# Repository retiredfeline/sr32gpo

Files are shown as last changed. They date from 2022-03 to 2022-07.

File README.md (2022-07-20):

# Shift register 32 general purpose output board

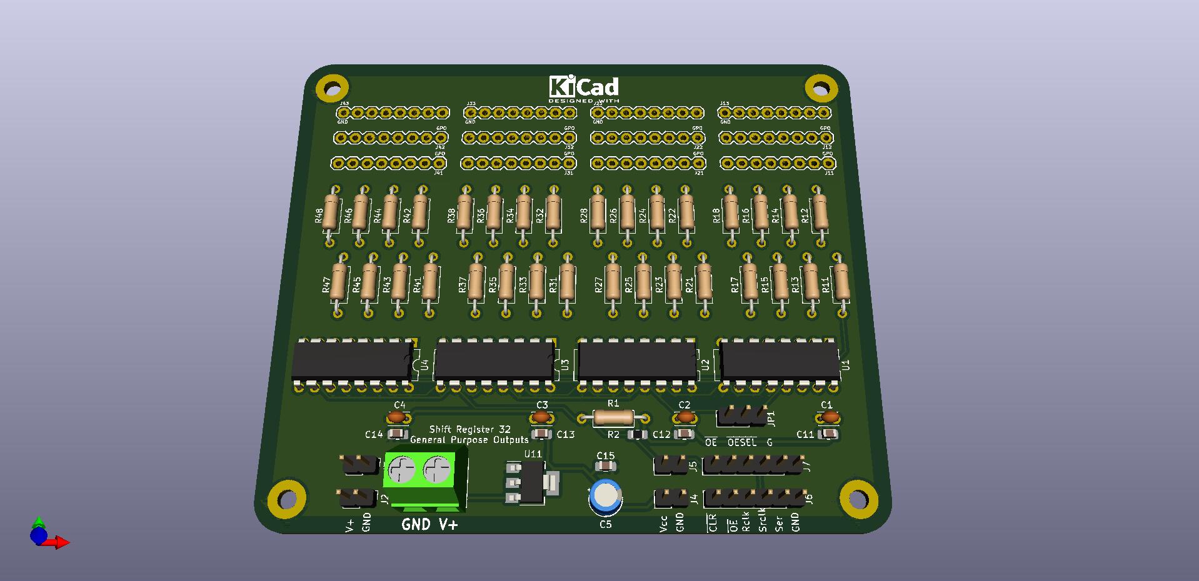
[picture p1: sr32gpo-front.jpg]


These are the Kicad design files for the Shift register 32 bit general purpose output board described in my [Hackaday project page](https://hackaday.io/project/184239-3-line-to-32-line-output-expander).

## Versioning

THT version February 2022

## Notes

The minimum lines required to use this board are: GND, SER (data), SRCLK (shift), RCLK (strobe). Vcc depends on the power arrangement. You should jumper the ~OESEL (output enable select) to ground if you don't wish to disable the display by signal, or vary the output with PWM, from a controller. The ~SRCLR input is only needed for resetting the output by the controller.

This board is designed with optional aspects you can choose to include or not:

- As mentioned some lines don't need to be driven in smaller configurations.

- Between 1 and 4 74HC595s can be installed for 8-32 outputs, in steps of 8. Naturally only the resistors for the used outputs need to be installed.

- The 74HC595 can source or sink 6 mA current.

- The 74HC595 can operate between 2V and 6V. This can be chosen to suit the controller, e.g. 3.3V or 5V, and the power supply section if installed.

- The power supply section is optional. You can choose to power this from the controller. Or you could power the controller with this.

- Copper pads for data and output are duplicated so you can attach more connectors or even solder wires. The input power is also brought out to duplicate pads for piggybacking to other circuits, e.g. an auxiliary board.

- Although the connectors are rendered as vertical pin headers, you can use other kinds of connectors like pin sockets, or even solder wires to the pads.

## Authors

* **Ken Yap**

## License

See the [LICENSE](LICENSE.md) file for license rights and limitations (MIT).

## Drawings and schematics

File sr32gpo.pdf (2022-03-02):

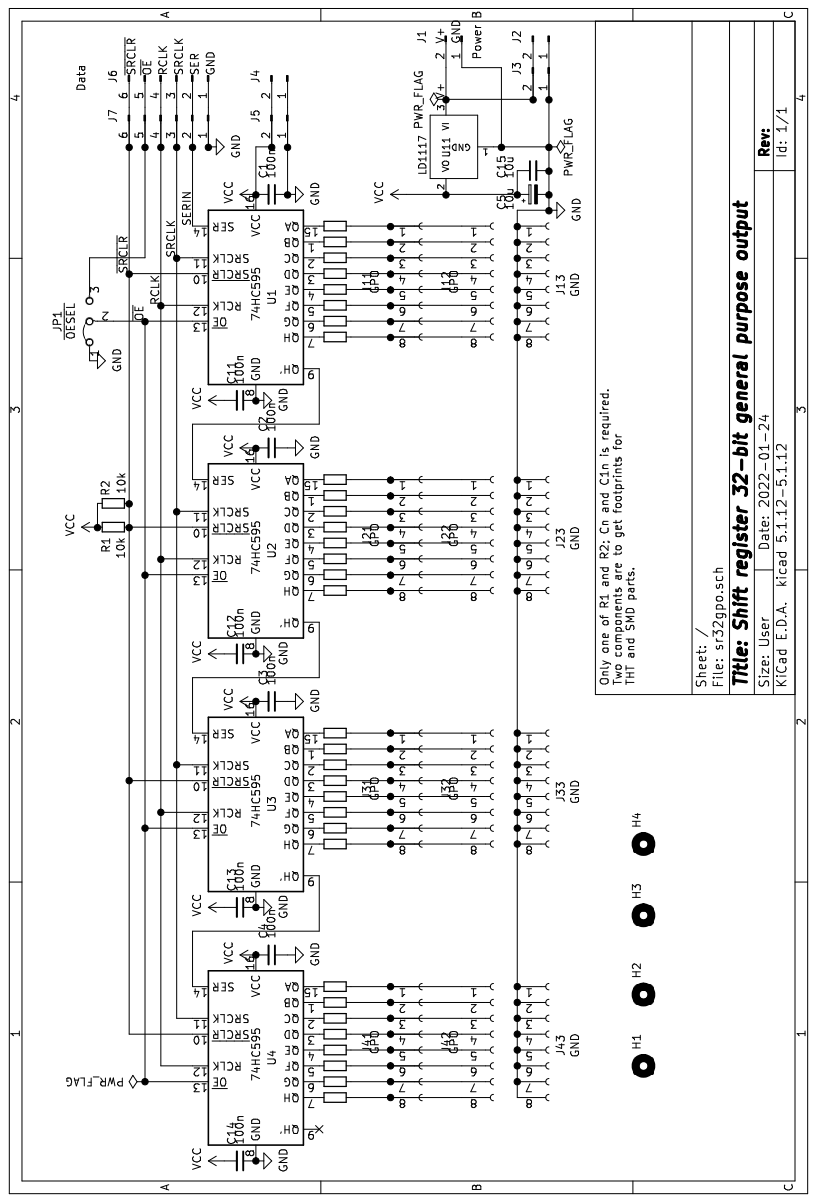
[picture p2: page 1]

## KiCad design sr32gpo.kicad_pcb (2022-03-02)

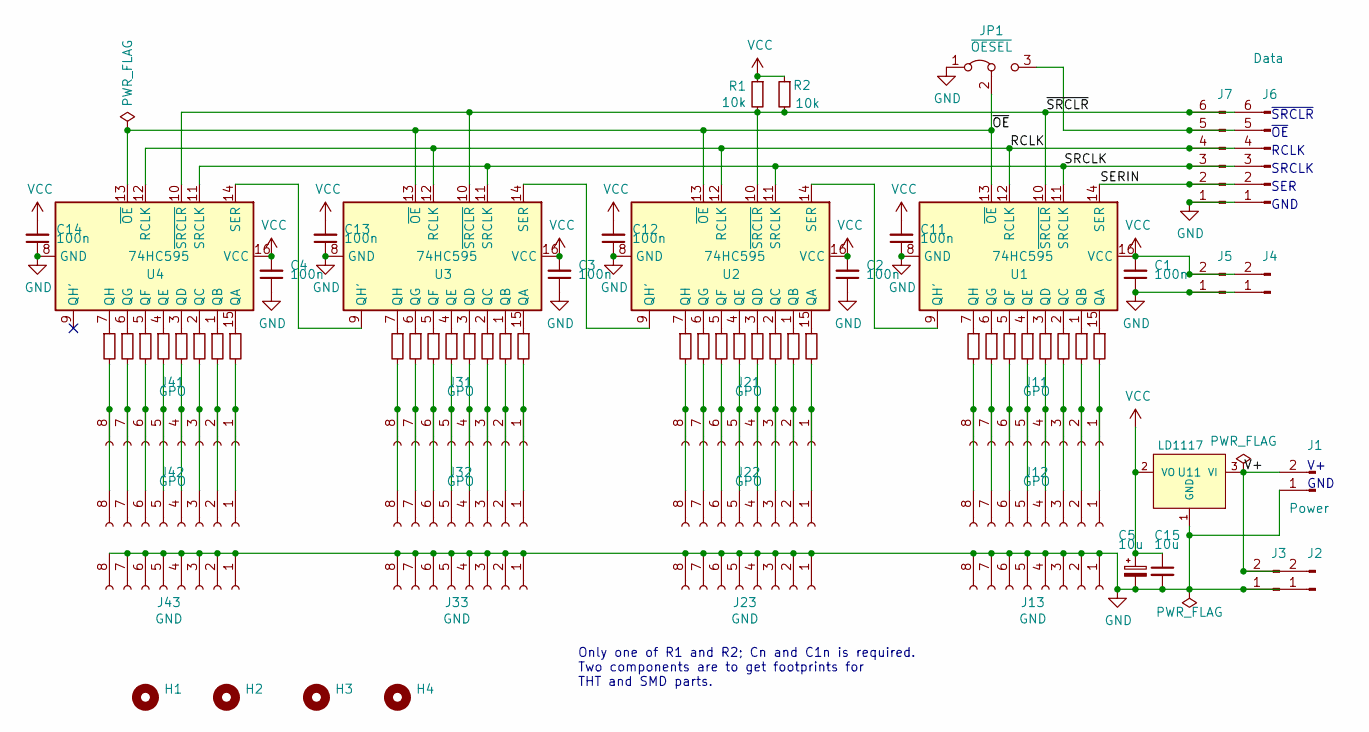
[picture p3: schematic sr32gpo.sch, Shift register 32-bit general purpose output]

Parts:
C1, C2, C3, C4: 100n; C_Disc_D3.0mm_W2.0mm_P2.50mm
C5: 10u; CP_Radial_D5.0mm_P2.50mm
C11, C12, C13, C14: 100n; C_0805_2012Metric_Pad1.18x1.45mm_HandSolder
C15: 10u; C_0805_2012Metric_Pad1.18x1.45mm_HandSolder
H1, H2, H3, H4: MountingHole_3mm_Pad
J1: Power; TerminalBlock_bornier-2_P5.08mm
J2, J3, J4, J5: Power; PinHeader_1x02_P2.54mm_Vertical
J6, J7: Data; PinHeader_1x06_P2.54mm_Vertical
J11, J12, J21, J22, J31, J32, J41, J42: GPO; 1X08
J13, J23, J33, J43: GND; 1X08
JP1: ~OESEL; PinHeader_1x03_P2.54mm_Vertical
R1: 10k; R_Axial_DIN0207_L6.3mm_D2.5mm_P10.16mm_Horizontal
R2: 10k; R_0805_2012Metric_Pad1.20x1.40mm_HandSolder
R11, R12, R13, R14, R15, R16, R17, R18, R21, R22, R23, R24, R25, R26, R27, R28, R31, R32, R33, R34, R35, R36, R37, R38, R41, R42, R43, R44, R45, R46, R47, R48: R_Axial_DIN0207_L6.3mm_D2.5mm_P10.16mm_Horizontal
U1, U2, U3, U4: 74HC595; DIP-16_W7.62mm
U11: LD1117; SOT-223-3_TabPin2

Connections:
/RCLK: J6.4, J7.4, U1.12 (RCLK), U2.12 (RCLK), U3.12 (RCLK), U4.12 (RCLK)
/SERIN: J6.2, J7.2, U1.14 (SER)
/SRCLK: J6.3, J7.3, U1.11 (SRCLK), U2.11 (SRCLK), U3.11 (SRCLK), U4.11 (SRCLK)
/V+: J1.2, J2.2, J3.2, U11.3 (VI)
/~OE: JP1.2 (C), U1.13 (~OE), U2.13 (~OE), U3.13 (~OE), U4.13 (~OE)
/~SRCLR: J6.6, J7.6, R1.2, R2.2, U1.10 (~SRCLR), U2.10 (~SRCLR), U3.10 (~SRCLR), U4.10 (~SRCLR)
GND: C1.1, C2.1, C3.1, C4.1, C5.2, C11.1, C12.1, C13.1, C14.1, C15.2, J1.1, J2.1, J3.1, J4.1, J5.1, J6.1, J7.1, J13.1, J13.2, J13.3, J13.4, J13.5, J13.6, J13.7, J13.8, J23.1, J23.2, J23.3, J23.4, J23.5, J23.6, J23.7, J23.8, J33.1, J33.2, J33.3, J33.4, J33.5, J33.6, J33.7, J33.8, J43.1, J43.2, J43.3, J43.4, J43.5, J43.6, J43.7, J43.8, JP1.1 (A), U1.8 (GND), U2.8 (GND), U3.8 (GND), U4.8 (GND), U11.1 (GND)
unnamed: J6.5, J7.5, JP1.3 (B)
unnamed: J11.1, J12.1, R11.2
unnamed: J11.2, J12.2, R12.2
unnamed: J11.3, J12.3, R13.2
unnamed: J11.4, J12.4, R14.2
unnamed: J11.5, J12.5, R15.2
unnamed: J11.6, J12.6, R16.2
unnamed: J11.7, J12.7, R17.2
unnamed: J11.8, J12.8, R18.2
unnamed: J21.1, J22.1, R21.2
unnamed: J21.2, J22.2, R22.2
unnamed: J21.3, J22.3, R23.2
unnamed: J21.4, J22.4, R24.2
unnamed: J21.5, J22.5, R25.2
unnamed: J21.6, J22.6, R26.2
unnamed: J21.7, J22.7, R27.2
unnamed: J21.8, J22.8, R28.2
unnamed: J31.1, J32.1, R31.2
unnamed: J31.2, J32.2, R32.2
unnamed: J31.3, J32.3, R33.2
unnamed: J31.4, J32.4, R34.2
unnamed: J31.5, J32.5, R35.2
unnamed: J31.6, J32.6, R36.2
unnamed: J31.7, J32.7, R37.2
unnamed: J31.8, J32.8, R38.2
unnamed: J41.1, J42.1, R41.2
unnamed: J41.2, J42.2, R42.2
unnamed: J41.3, J42.3, R43.2
unnamed: J41.4, J42.4, R44.2
unnamed: J41.5, J42.5, R45.2
unnamed: J41.6, J42.6, R46.2
unnamed: J41.7, J42.7, R47.2
unnamed: J41.8, J42.8, R48.2
unnamed: R11.1, U1.15 (QA)
unnamed: R12.1, U1.1 (QB)
unnamed: R13.1, U1.2 (QC)
unnamed: R14.1, U1.3 (QD)
unnamed: R15.1, U1.4 (QE)
unnamed: R16.1, U1.5 (QF)
unnamed: R17.1, U1.6 (QG)
unnamed: R18.1, U1.7 (QH)
unnamed: R21.1, U2.15 (QA)
unnamed: R22.1, U2.1 (QB)
unnamed: R23.1, U2.2 (QC)
unnamed: R24.1, U2.3 (QD)
unnamed: R25.1, U2.4 (QE)
unnamed: R26.1, U2.5 (QF)
unnamed: R27.1, U2.6 (QG)
unnamed: R28.1, U2.7 (QH)
unnamed: R31.1, U3.15 (QA)
unnamed: R32.1, U3.1 (QB)
unnamed: R33.1, U3.2 (QC)
unnamed: R34.1, U3.3 (QD)
unnamed: R35.1, U3.4 (QE)
unnamed: R36.1, U3.5 (QF)
unnamed: R37.1, U3.6 (QG)
unnamed: R38.1, U3.7 (QH)
unnamed: R41.1, U4.15 (QA)
unnamed: R42.1, U4.1 (QB)
unnamed: R43.1, U4.2 (QC)
unnamed: R44.1, U4.3 (QD)
unnamed: R45.1, U4.4 (QE)
unnamed: R46.1, U4.5 (QF)
unnamed: R47.1, U4.6 (QG)
unnamed: R48.1, U4.7 (QH)
unnamed: U1.9 (QH'), U2.14 (SER)
unnamed: U2.9 (QH'), U3.14 (SER)
unnamed: U3.9 (QH'), U4.14 (SER)
VCC: C1.2, C2.2, C3.2, C4.2, C5.1, C11.2, C12.2, C13.2, C14.2, C15.1, J4.2, J5.2, R1.1, R2.1, U1.16 (VCC), U2.16 (VCC), U3.16 (VCC), U4.16 (VCC), U11.2 (VO)

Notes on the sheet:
GND
SER
SRCLK
RCLK
~SRCLR
~OE~
Only one of R1 and R2; Cn and C1n is required. Two components are to get footprints for THT and SMD parts.

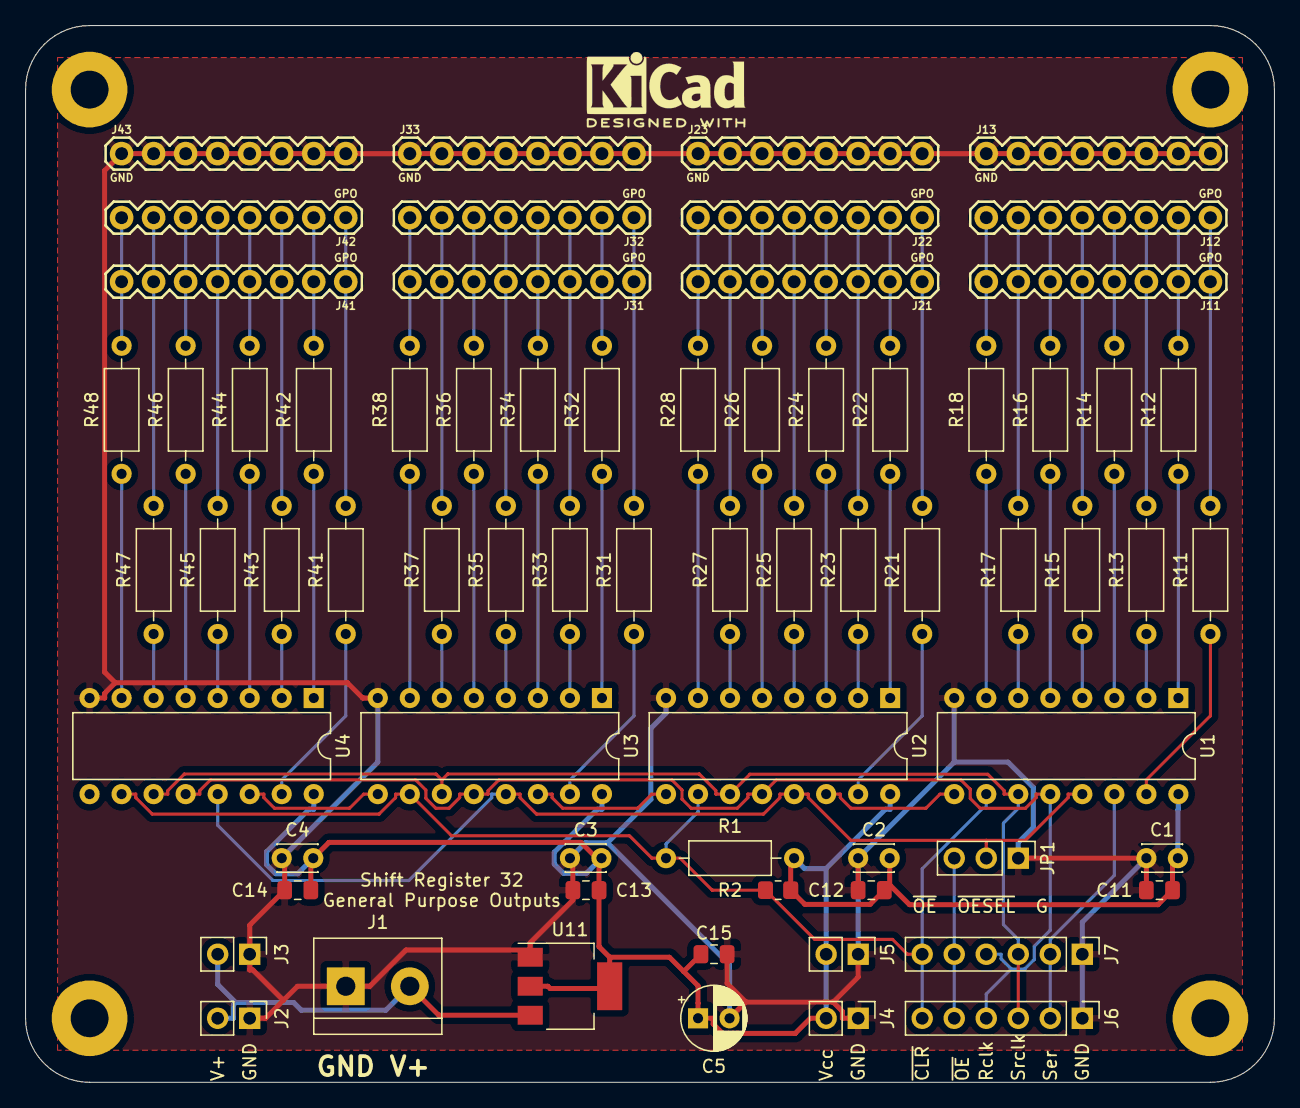
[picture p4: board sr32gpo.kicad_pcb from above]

Board: 2 copper layers, 99.1 x 83.8 mm, 73 parts (0 on the bottom side), 76 nets.
